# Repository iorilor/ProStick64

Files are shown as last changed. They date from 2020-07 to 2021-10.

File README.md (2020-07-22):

# ProStick64

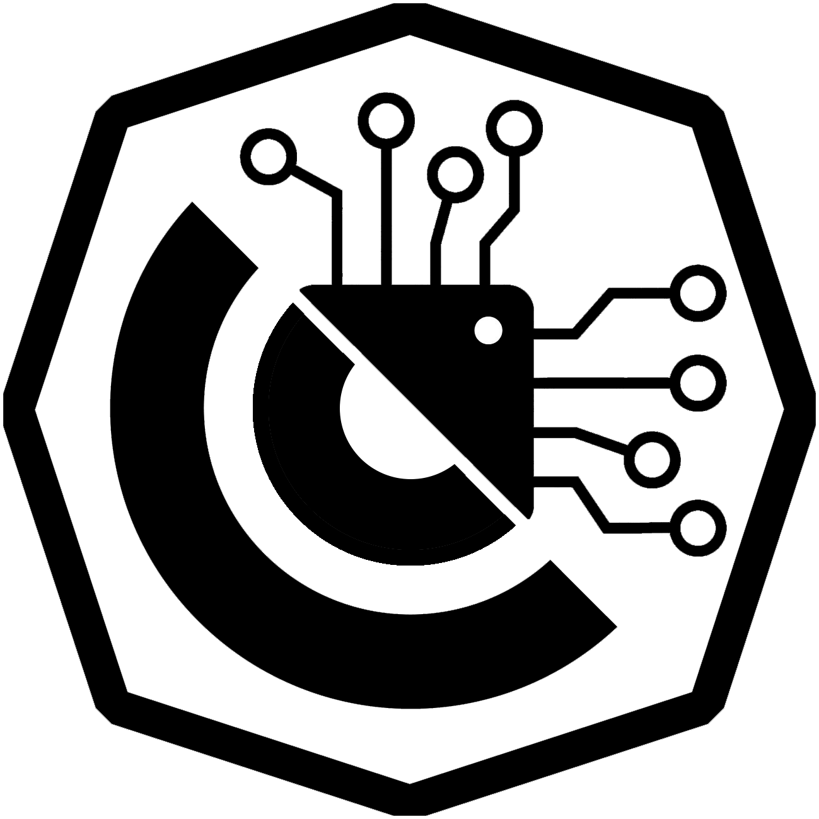
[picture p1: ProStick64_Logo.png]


This repository contains everything about the ProStick64 stick replacement module and more!
This is what you can find inside the various folders:
* datasheets:     datasheets of the various electronic components used on the board
* documentation:  useful documents and application notes regarding the STM32G0 MCU
* media:          Images and other media related to ProStick64
* PCB:            PCB gerber files, KICAD project and libraries
* render:         STL files of the enclosure and thumbstick
* source:         Source code of the software

Note: if you want to edit the source code I suggest you to import the source folders inside STM32CubeIDE software.
For any additional info contact me at info@prostick64.com

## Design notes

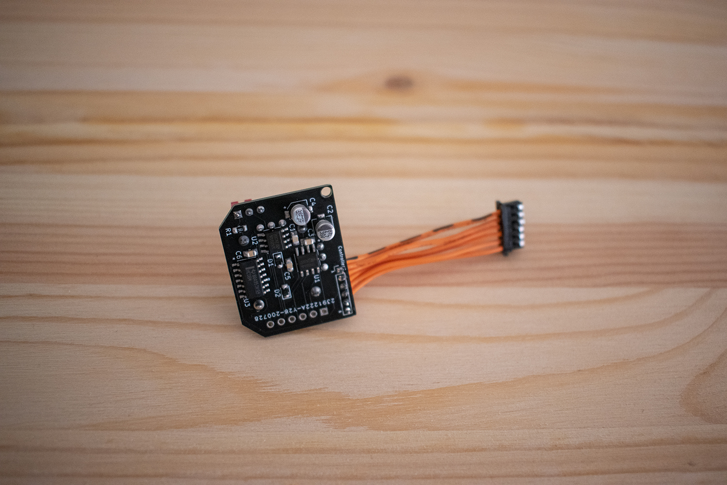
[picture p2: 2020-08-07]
media/v0_5/CUrear.jpg

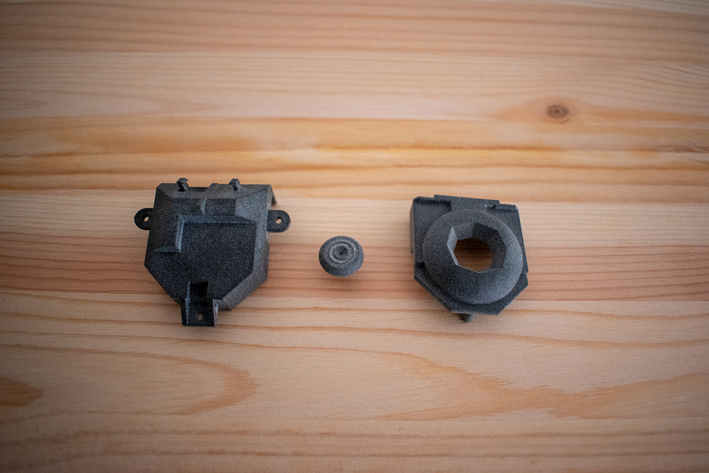
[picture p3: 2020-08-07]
media/v0_5/Case.jpg

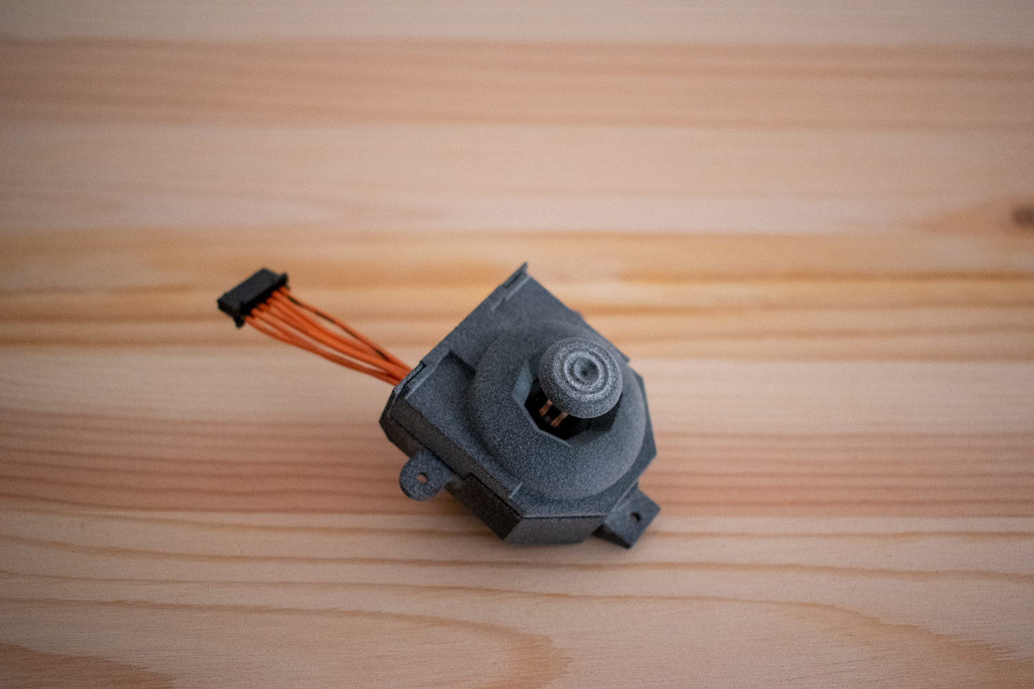
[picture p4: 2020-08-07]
media/v0_5/FullModule.jpg

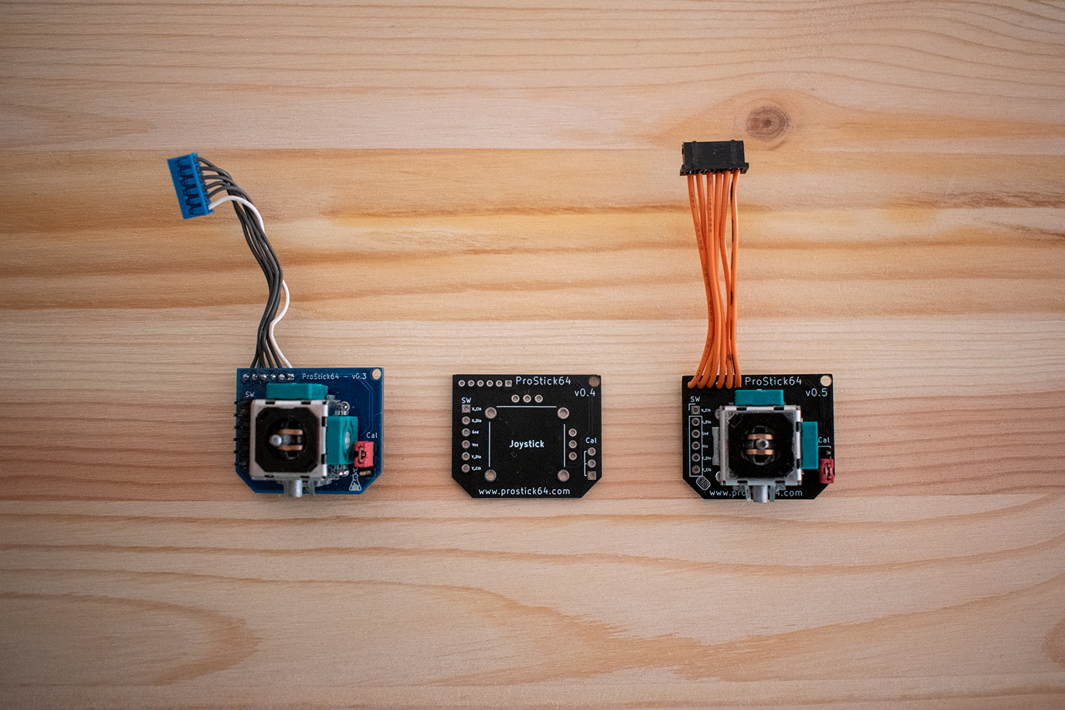
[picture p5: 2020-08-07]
media/v0_5/Front.jpg

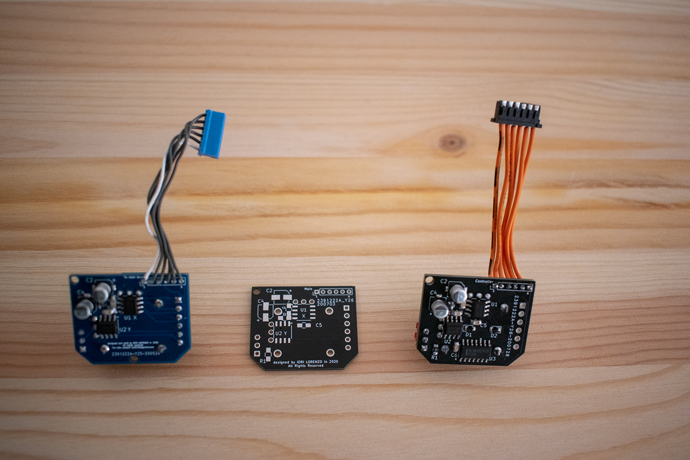
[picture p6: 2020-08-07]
media/v0_5/rear.jpg

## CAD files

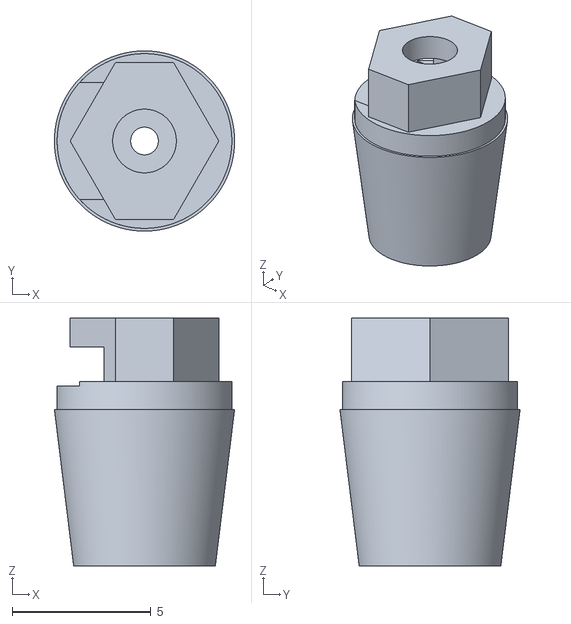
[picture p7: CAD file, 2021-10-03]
render/Stick_Shaft v5.stl
6.50 x 6.50 x 8.95

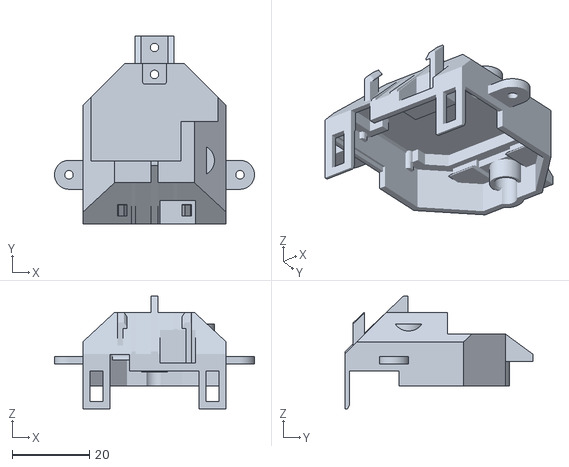
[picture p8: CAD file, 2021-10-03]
render/Enclosure Back v12.stl
51.7 x 48.7 x 29.2

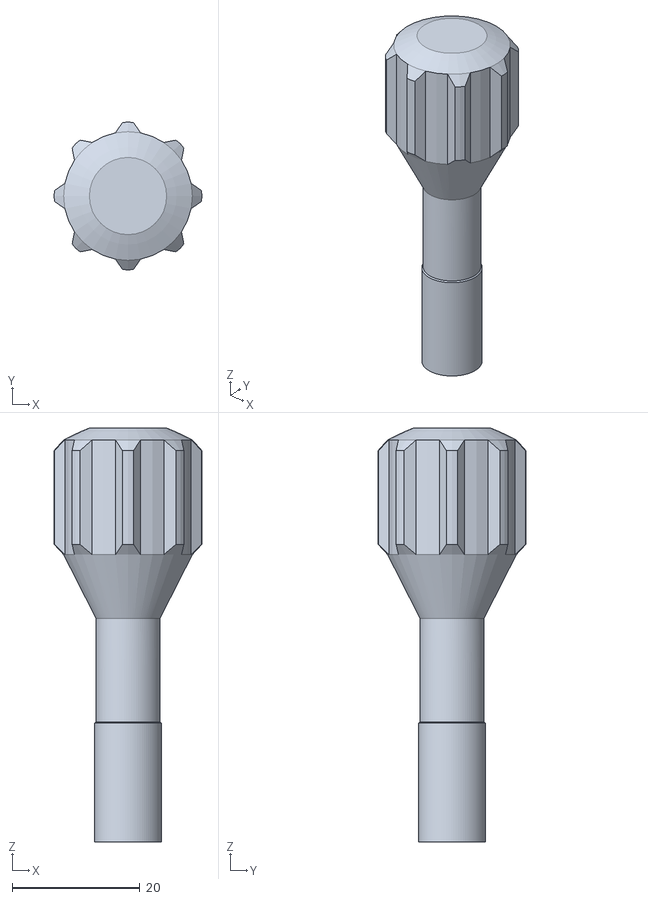
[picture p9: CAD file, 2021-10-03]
render/Bit Holder.stl
23.2 x 23.2 x 64.9

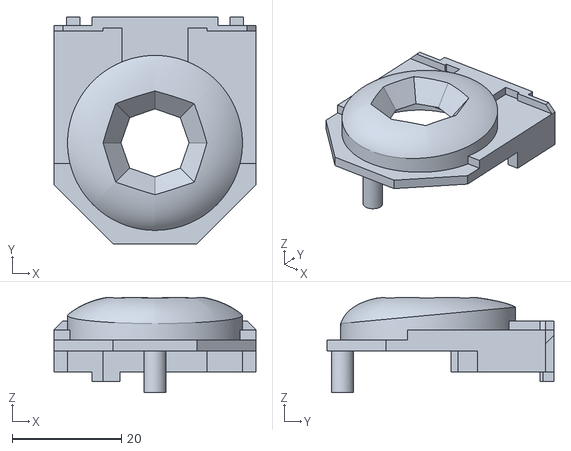
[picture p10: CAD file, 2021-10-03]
render/Enclosure Top v13.stl
37.0 x 41.5 x 17.4

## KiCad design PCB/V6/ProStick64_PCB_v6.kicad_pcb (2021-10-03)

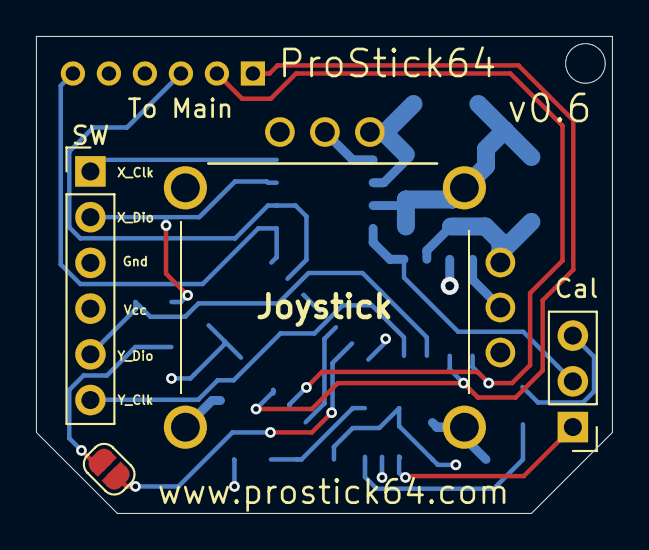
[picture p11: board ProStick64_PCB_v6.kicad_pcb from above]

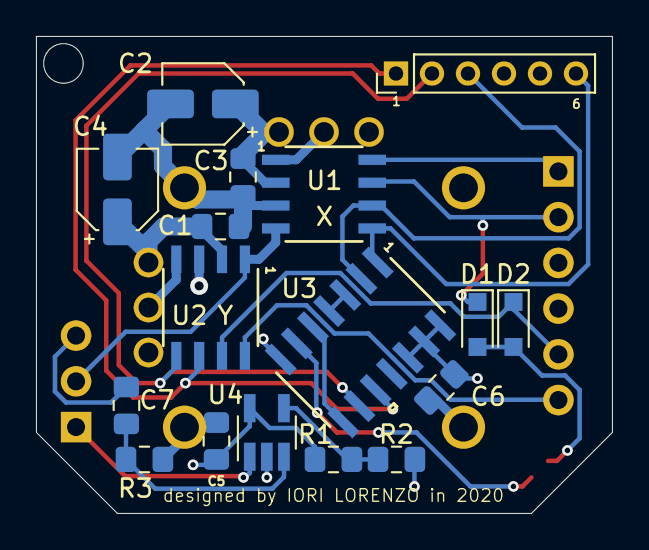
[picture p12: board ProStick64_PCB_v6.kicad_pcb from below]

Board: 4 copper layers, 32.0 x 26.5 mm, 21 parts (17 on the bottom side), 20 nets.

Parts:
C1, C3, C5, C6, C7: 0.1uF; C_0805_2012Metric_Pad1.15x1.40mm_HandSolder
C2, C4: 4.7uF; CP_Elec_4x5.3
Cal: CAL_SW; PinHeader_1x03_P2.54mm_Vertical
D1, D2: BAS316; D_SOD-323_HandSoldering
JP1: SolderJumper_2_Open; SolderJumper-2_P1.3mm_Open_RoundedPad1.0x1.5mm
Joystick: RKJXK122000D
R1: 4.75k; R_0805_2012Metric_Pad1.15x1.40mm_HandSolder
R2, R3: 30k; R_0805_2012Metric_Pad1.15x1.40mm_HandSolder
SW: Serial Wire; PinHeader_1x06_P2.54mm_Vertical
To Main: TO MAIN BOARD; PinHeader_1x06_P2.00mm_Vertical
U1: X; STM32G0_SO8_T2
U2: Y; STM32G0_SO8_T2
U3: CD74HC08M
U4: TS861AIL; SOT-23-5_HandSoldering

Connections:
/Vcc: C1.1, C2.1, C3.1, C4.1, C5.1, C6.1, C7.1, Cal.3, Joystick.3, Joystick.6, R1.2, SW.4, To Main.5, U1.2, U2.2, U3.12, U3.13, U3.14, U4.5
/X0: To Main.6, U1.5, U3.1
/X1: To Main.3, U1.6, U3.2
/Y0: To Main.2, U2.5, U3.9
/Y1: To Main.1, U2.6, U3.10
/cal: Cal.2, U1.4, U2.1
/x_dio: D1.1, SW.2, U1.7
/y_dio: D2.1, SW.5, U2.7
GND: C1.2, C2.2, C3.2, C4.2, C5.2, C6.2, Joystick.1, Joystick.4, Joystick.GND, R2.1, R3.2, SW.3, To Main.4, U1.3, U2.3, U3.7, U4.2
unnamed: C7.2, R3.1, U4.3
unnamed: D1.2, D2.2, JP1.1
unnamed: SW.1, U1.8
unnamed: SW.6, U2.8
unnamed: Cal.1, U4.1
unnamed: JP1.2, U3.6
unnamed: R1.1, R2.2, U4.4
unnamed: Joystick.2, U1.1
unnamed: Joystick.5, U2.4
unnamed: U3.3, U3.4
unnamed: U3.5, U3.8

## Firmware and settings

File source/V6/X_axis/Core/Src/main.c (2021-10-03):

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

/* Includes ------------------------------------------------------------------*/
#include "main.h"
#include "math.h"

/* USER CODE BEGIN PD */
#define MAX_RANGE    	83			//Maximum number of steps in every direction
#define MAX_RANGE_EXT 	100			//Maximum number of steps in every direction (ext)
#define DEADZONE      	250			//Area that will be ignored (0-2048)
#define AVG_PRECISION	128			//Number of averaged measurements for every getValue()
/* USER CODE END PD */

ADC_HandleTypeDef hadc1;

void SystemClock_Config(void);
static void MX_GPIO_Init(void);
static void MX_ADC1_Init(void);
/* USER CODE BEGIN PFP */
int16_t 	getCalFlashSlot		(void);
void 		calibration			(uint8_t, uint8_t);
void 		draw			    (int16_t);
void 		writeToFlash	  	(uint32_t, uint32_t, uint8_t);
void 		eraseFlash 		  	(void);
uint16_t 	getValue		    (void);
void		rotateLeft 		  	(volatile uint32_t*);
void		rotateRight 	  	(volatile uint32_t*);
void		swdioInput      	(void);
uint16_t	getValueKalman		(float*, float*, float*, float*);
void		kalWait				(uint16_t, float*, float*, float*, float*);

/* USER CODE END PFP */

/* USER CODE BEGIN 0 */
volatile uint32_t* FLASH_SR  	  = (uint32_t*)0x40022010;  //MEMORY ADDRESSES
volatile uint32_t* FLASH_CR  	  = (uint32_t*)0x40022014;
volatile uint32_t* PAGE15_SLOT1   = (uint32_t*)0x08007800;
volatile uint32_t* GPIOA_IDR 	  = (uint32_t*)0x50000010;
volatile uint32_t* GPIOB_IDR 	  = (uint32_t*)0x50000410;
volatile uint32_t* GPIOA_ODR 	  = (uint32_t*)0x50000014;
volatile uint32_t* ADC_ISR 		  = (uint32_t*)0x40012400;
volatile uint32_t* ADC_DR 		  = (uint32_t*)0x40012440;
/* USER CODE END 0 */

/**
  * @brief  The application entry point.
  * @retval int
  */
int main(void)
{
  /* MCU Configuration--------------------------------------------------------*/

  /*Reset of all peripherals, Initializes the Flash interface and the Systick.*/
  HAL_Init();

  /* Configure the system clock */
  SystemClock_Config();

  /* Initialize all configured peripherals */
  MX_GPIO_Init();
  MX_ADC1_Init();
  /* USER CODE BEGIN 2 */
  HAL_ADC_Start(&hadc1);
  //The next line configures the output register with the bit wheel
  *GPIOA_ODR = (*GPIOA_ODR & 0xFFFF0000) + 0x6600;
  uint16_t calSwRead = (uint16_t)(*GPIOA_IDR) & 0x1; //calSw = GPIOA_PIN0 status
  uint8_t  calSw = 0;
  if (calSwRead) calSw = 1;
  int16_t 	calFlashSlot = getCalFlashSlot();

  //If getCalFlashSlot returns -1 it means there is no calibration data stored
  if (calFlashSlot == -1) calibration(calSw, 0);

  //If it returns 255 it means the memory is full. Erase + calibration needed.
  if (calFlashSlot == 255){
    eraseFlash();
    calibration(calSw, 0);
  }
  uint32_t 	w1 = *(PAGE15_SLOT1 + ((calFlashSlot)*2));
  uint32_t 	w2 = *(PAGE15_SLOT1 + ((calFlashSlot)*2) + 1);
  uint16_t 	w1a = (uint16_t)(w1>>16);
  uint16_t 	neutral16 = (uint16_t) w1;
  uint16_t 	calFactAInt = (uint16_t)(w2>>16);
  uint16_t 	calFactBInt = (uint16_t) w2;
  uint16_t 	min = w1a & 0x7FFF;
  uint8_t  	calSwOld = (uint8_t)(w1a >> 15);
  if (calSwOld != calSw){
  	calFlashSlot++;
    calibration(calSw, (uint8_t)calFlashSlot);
  }
  float    	calFactA = (float)calFactAInt / 10000;
  float    	calFactB = (float)calFactBInt / 10000;

  uint16_t 	value16, value16Old, value16Raw;
  float		valueFloat = 0;
  int16_t 	steps = 0;
  uint16_t	stepScale = 0;
  value16Old = 2048;
  value16Raw = getValue();
  if (value16Raw < 1500 || value16Raw > 2500){
	  stepScale = 4096 / (MAX_RANGE_EXT * 2);
  } else {
	  stepScale = 4096 / (MAX_RANGE * 2);
  }
  HAL_Delay(1000);
    /* USER CODE END 2 */

    /* Infinite loop */
    /* USER CODE BEGIN WHILE */
    while (1)
    {
  	  value16Raw = getValue();
  	  if (value16Raw < neutral16){
  		  if (value16Raw < min) value16Raw = min;
  		  valueFloat = value16Raw - min;
  		  valueFloat = valueFloat * calFactA;
  		  if (valueFloat >= (2048 - DEADZONE)) valueFloat = 2048 - DEADZONE;
  		  valueFloat = (valueFloat / (2048 - DEADZONE)) * 2048;
  		  value16 = (uint16_t)valueFloat;
  	  }
  	  else if (value16Raw == neutral16)	value16 = neutral16;
  	  else if (value16Raw > neutral16){
  		  valueFloat = value16Raw - neutral16;
  		  valueFloat = valueFloat * calFactB;
  		  if (valueFloat <= (DEADZONE)) valueFloat = DEADZONE;
  		  valueFloat = ((valueFloat - DEADZONE)/(2048 - DEADZONE))*2048;
  		  value16 = (uint16_t)valueFloat + 2048;
  	  }
  	  if (value16 > 4096) value16 = 4096;
  	  if (value16 < 0) value16 = 0;
  	  steps = steps + ((int16_t)value16 - value16Old);
  	  value16Old = value16;
  	  while (steps < -stepScale){
  		  rotateLeft(GPIOA_ODR);
  		  steps = steps + stepScale;
  	  }
  	  while (steps > stepScale){
  		  rotateRight(GPIOA_ODR);
  		  steps = steps - stepScale;
  	  }

    /* USER CODE END WHILE */

    /* USER CODE BEGIN 3 */
  }
  /* USER CODE END 3 */
}

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
/* USER CODE BEGIN 4 */

//Find the FLASH memory slot currently in use
int16_t getCalFlashSlot(void){
	int16_t i = 0;
	uint32_t data = *PAGE15_SLOT1;
	while (((data != 0xFFFFFFFF) && i < 256)){
		i++;
		data = *(PAGE15_SLOT1 + i*2);
	}
	return i-1;
}
//Calibration 4.0
void calibration(uint8_t calSw, uint8_t calFlashSlot){

//PHASE 1 - Calculating neutral value
uint32_t 	i=0, neutral32=0, w1=0xFFFFFFFF,w2=0xFFFFFFFF;
uint16_t 	value16=0, count=0, neutralAverage=0, neutralAverageOld=0;
uint16_t  	max=0, min=0, MCU_OK=0;
uint16_t 	w1a=0xFFFF, w1b=0xFFFF, w2a=0xFFFF, w2b=0xFFFF;
uint8_t		neutralOK=0;
int8_t		dir=0;
float		calFactA=0.0, calFactB=0.0;

//Kalman filter variables definition
float 		kal_est_e = 2.0, kal_mea_e = 2.0, kal_q = 0.01;
float		kal_last_est = (float) getValue();

HAL_Delay(5000);

swdioInput();

//Set GPIOA_PIN11 and PIN12 HIGH to communicate that MCU is ready to proceed
*GPIOA_ODR = (*GPIOA_ODR & 0xFFFF0000) + 0x1800;

//Wait until GPIOA_PIN13 becomes 1 - both MCUs are ready to proceed
i=0;
while (i<1000){
	while (!MCU_OK){
		i=0;
		MCU_OK = (uint16_t)(*GPIOA_IDR) & 0x2000;
	}
	i++;
	HAL_Delay(1);
	MCU_OK = (uint16_t)(*GPIOA_IDR) & 0x2000;
}
kalWait(700, &kal_est_e, &kal_mea_e, &kal_last_est, &kal_q);

//The next line reconfigures the output register with the bit wheel
*GPIOA_ODR = (*GPIOA_ODR & 0xFFFF0000) + 0x6600;

MCU_OK = 0;
draw(3);

value16 = getValueKalman(&kal_est_e, &kal_mea_e, &kal_last_est, &kal_q);

while (value16<1600 || value16>2400){   //Wait for joystick to be centered
	value16 = getValueKalman(&kal_est_e, &kal_mea_e, &kal_last_est, &kal_q);
}
//Step 1.1 - Pull the stick to any corner and let go until neutral is OK
while (neutralOK<3){
	count++;
	while (value16>1500 && value16<2500){  //Wait for joystick to be moved
		value16 = getValueKalman(&kal_est_e, &kal_mea_e, &kal_last_est, &kal_q);
	}
	kalWait(1300, &kal_est_e, &kal_mea_e, &kal_last_est, &kal_q);
	value16 = getValueKalman(&kal_est_e, &kal_mea_e, &kal_last_est, &kal_q);
	if (value16>2500) dir=1;
	else if (value16<1500) dir=-1;
	while (value16<1600 || value16>2400){  //Wait for joystick to return centered
		value16 = getValueKalman(&kal_est_e, &kal_mea_e, &kal_last_est, &kal_q);
	}
	kalWait(1300, &kal_est_e, &kal_mea_e, &kal_last_est, &kal_q);	//Wait for spring to stabilize
	value16 = getValueKalman(&kal_est_e, &kal_mea_e, &kal_last_est, &kal_q);
	neutral32 = neutral32 + value16;	 //Add current neutral reading to pool
	neutralAverage = (neutral32/count);
	if (neutralAverage == neutralAverageOld) neutralOK++;
	else neutralOK = 0;
	neutralAverageOld = neutralAverage;
	if (dir==1) 		draw(-2);
	else if (dir==-1) 	draw(-3);
}
//Set GPIOA_PIN11 and PIN12 HIGH to communicate that MCU is ready to proceed
*GPIOA_ODR = (*GPIOA_ODR & 0xFFFF0000) + 0x1800;

//Wait until GPIOA_PIN13 becomes 1 - both MCUs are ready to proceed
i=0;
while (i<1000){
	while (!MCU_OK){
		i=0;
		MCU_OK = (uint16_t)(*GPIOA_IDR) & 0x2000;
	}
	i++;
	HAL_Delay(1);
	MCU_OK = (uint16_t)(*GPIOA_IDR) & 0x2000;
}

kalWait(700, &kal_est_e, &kal_mea_e, &kal_last_est, &kal_q);

//The next line reconfigures the output register with the bit wheel
*GPIOA_ODR = (*GPIOA_ODR & 0xFFFF0000) + 0x6600;

MCU_OK = 0;
draw(3);
//PHASE 2 - Calculating min and max while the stick is rotated
min = neutralAverage;
max = neutralAverage;
for (i=0; i<100000; i++){
	value16 = getValueKalman(&kal_est_e, &kal_mea_e, &kal_last_est, &kal_q);
	if (value16 > max){
		max = value16;
	}else if(value16 < min){
		min = value16;
	}
}
//PHASE 3 - Calculating calFactA and calFactB
calFactA = ((float)2047) / (neutralAverage - min);
calFactB = ((float)2048) / (max - neutralAverage);
//PHASE 4 - Calculating w1 and w2 and write to flash
/* Calibration data structure:

	w1 = 						w1a								  w1b
				|--1bit--|---------15bit----------|---------------16bit---------------|
				  calSw				min							neutral16

	w2 =						w2a									w2b
				|--------------16bit--------------|---------------16bit---------------|
							 calFactA							calFactB
*/
w1a = min + ((uint16_t)calSw << 15);
w1b = neutralAverage;
w2a = (uint16_t)(calFactA * 10000);
w2b = (uint16_t)(calFactB * 10000);
w1 = ((uint32_t)w1a << 16) + w1b;
w2 = ((uint32_t)w2a << 16) + w2b;
writeToFlash(w1, w2, calFlashSlot);

//Set GPIOA_PIN11 and PIN12 HIGH to communicate that MCU is ready to proceed
*GPIOA_ODR = (*GPIOA_ODR & 0xFFFF0000) + 0x1800;

//Wait until GPIOA_PIN13 becomes 1 - both MCUs are ready to proceed
i=0;
while (i<1000){
	while (!MCU_OK){
		i=0;
		MCU_OK = (uint16_t)(*GPIOA_IDR) & 0x2000;
	}
	i++;
	HAL_Delay(1);
	MCU_OK = (uint16_t)(*GPIOA_IDR) & 0x2000;
}

HAL_Delay(100);

//The next line reconfigures the output register with the bit wheel
*GPIOA_ODR = (*GPIOA_ODR & 0xFFFF0000) + 0x6600;

MCU_OK = 0;
draw(-1);
}

//Move the cursor in a waving pattern for n times
void draw(int16_t n){
	uint8_t  i=0;
  uint16_t j=0;
  //if times_to_repeat = -1 loop indefinitely
  if (n == -1){
    while(1){
      for (i=0; i<40; i++){
  			rotateRight(GPIOA_ODR);
  			HAL_Delay(1);
  		}
  		HAL_Delay(500);
  		for (i=0; i<40; i++){
  			rotateLeft(GPIOA_ODR);
  			HAL_Delay(1);
  		}
  		for (i=0; i<40; i++){
  			rotateLeft(GPIOA_ODR);
  			HAL_Delay(1);
  		}
  		HAL_Delay(500);
  		for (i=0; i<40; i++){
  			rotateRight(GPIOA_ODR);
  			HAL_Delay(1);
  		}
    }
  }
  //if times_to_repeat = -2 perform a quick draw cycle to the right
  if (n == -2){
		  for (i=0; i<20; i++){
			  rotateRight(GPIOA_ODR);
			  HAL_Delay(1);
		  }
		  HAL_Delay(100);
		  for (i=0; i<20; i++){
			  rotateLeft(GPIOA_ODR);
			  HAL_Delay(1);
		  }
  }
  //if times_to_repeat = -3 perform a quick draw cycle to the left
  if (n == -3){
 		  for (i=0; i<20; i++){
 			  rotateLeft(GPIOA_ODR);
 			  HAL_Delay(1);
 		  }
 		  HAL_Delay(100);
 		  for (i=0; i<20; i++){
 			  rotateRight(GPIOA_ODR);
 			  HAL_Delay(1);
 		  }
   }
  //otherwise loop n times
  else {
  	for (j=0; j<n; j++){
  		for (i=0; i<40; i++){
  			rotateRight(GPIOA_ODR);
  			HAL_Delay(1);
  		}
  		HAL_Delay(500);
  		for (i=0; i<40; i++){
  			rotateLeft(GPIOA_ODR);
  			HAL_Delay(1);
  		}
  		for (i=0; i<40; i++){
  			rotateLeft(GPIOA_ODR);
  			HAL_Delay(1);
  		}
  		HAL_Delay(500);
  		for (i=0; i<40; i++){
  			rotateRight(GPIOA_ODR);
  			HAL_Delay(1);
  		}
  	}
  }
}

//Write data into MCU flash memory
void writeToFlash(uint32_t w1, uint32_t w2, uint8_t calFlashSlot){

	HAL_FLASH_Unlock();
	while (*FLASH_SR&(1<<16));          			    //wait for BSY1 flag to be 0
	*FLASH_SR = *FLASH_SR & 0x00050000; 			    //reset all flash error flags
	while (*FLASH_SR&(1<<18));          			    //wait for CFGBSY1 flag to be 0
	*FLASH_CR = *FLASH_CR | 0x01; 					      //set PG flag
	*(PAGE15_SLOT1 + (calFlashSlot*2)) = w1;      //write w1 into Flash
	__ISB();				//Ensures that the two 32bit words are not merged by compiler
	*(PAGE15_SLOT1 + (calFlashSlot*2) + 1) = w2;  //write w2 into Flash
	while (*FLASH_SR&(1<<16));          			    //wait for BSY1 flag to be 0
	while (*FLASH_SR&(1<<18));          			    //wait for CFGBSY1 flag to be 0
	*FLASH_CR = *FLASH_CR & 0xFFFFFFFE;			     	//reset PG flag
	HAL_FLASH_Lock();
}

//Erase all data in pages 15 and 16 of MCU flash memory
void eraseFlash (void){
	HAL_FLASH_Unlock();
	while (*FLASH_SR&(1<<16));          	//wait for BSY1 flag to be 0
	*FLASH_SR = *FLASH_SR & 0x00050000; 	//reset all flash error flags
	*FLASH_CR = *FLASH_CR & 0xC0000000; 	//reset page erase and number flags
	*FLASH_CR = *FLASH_CR | 0x7A; 				//set page erase flag and page number 15
	*FLASH_CR = *FLASH_CR | (1<<16);    	//set start flag
	while (*FLASH_SR&(1<<16));          	//wait for BSY1 flag to be 0
	*FLASH_CR = *FLASH_CR & 0xC0000000; 	//reset page erase and number flags
	HAL_FLASH_Lock();
}

//Wait till new value is available from ADC data register and read it
uint16_t getValue(void){
  uint32_t value = 0;
  uint16_t i;
  for (i=0; i<AVG_PRECISION; i++){
	while (!(*ADC_ISR & 1<<3));
	value = value + (uint16_t)(*ADC_DR);
  }
  value = value / AVG_PRECISION;
  return (uint16_t) value;
}

//Simulate an optical disc rotation (LEFT)
void rotateLeft (volatile uint32_t* GPIOA_ODR){
	uint8_t result, data;
	data = (uint8_t)(*(GPIOA_ODR)>>8);
	if ( data & 1<<7 ){
		result = (data<<1)|(1<<0);
	}else{
		result = (data<<1);
	}
	*GPIOA_ODR = (*GPIOA_ODR & 0xFFFF00FF) + ((uint16_t)result << 8);
}

//Simulate an optical disc rotation (RIGHT)
void rotateRight (volatile uint32_t* GPIOA_ODR){
	uint8_t result, data;
	data = (uint8_t)(*(GPIOA_ODR)>>8);
	if ( data & (1<<0) ){
		result = (data>>1)|(1<<7);
	}else{
		result = (data>>1);
	}
	*GPIOA_ODR = (*GPIOA_ODR & 0xFFFF00FF) + ((uint16_t)result << 8);
}

//Configure SWDIO pin (GPIOA_PIN13) as input
void swdioInput (void){
  GPIO_InitTypeDef GPIO_InitStruct = {0};
  GPIO_InitStruct.Pin  = GPIO_PIN_13;
  GPIO_InitStruct.Mode = GPIO_MODE_INPUT;
  GPIO_InitStruct.Pull = GPIO_PULLDOWN;
  HAL_GPIO_Init(GPIOA, &GPIO_InitStruct);
}

uint16_t getValueKalman(float* est_e, float* mea_e, float* last_est, float* q){

	float kal_gain, est;

	kal_gain = (*est_e) / ((*est_e) + (*mea_e));
	est = (*last_est) + (kal_gain * (getValue() - (*last_est)));
	(*est_e) = ((1.0 - kal_gain) * (*est_e)) + (fabs((*last_est) - est) * (*q));
	(*last_est) = est;
	return (uint16_t)(est + 0.5);
}

void kalWait(uint16_t times, float* est_e, float* mea_e, float* last_est, float* q){
	uint16_t i;
	for (i=0; i<times; i++){
	getValueKalman(est_e, mea_e, last_est, q);
	}
}

/* USER CODE END 4 */
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


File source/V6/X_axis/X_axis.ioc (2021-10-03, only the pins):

Mcu.UserName=STM32G031J6Mx
PA0.GPIO_Label=CAL_SW
PA0.Signal=GPIO_Input
PA13.Signal=SYS_SWDIO
PA14-BOOT0.Signal=SYS_SWCLK
PB7.GPIO_Label=AXIS_IN
PB7.Signal=ADC1_IN11

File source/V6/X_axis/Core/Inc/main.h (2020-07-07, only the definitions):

#define AXIS_IN_Pin GPIO_PIN_7
#define AXIS_IN_GPIO_Port GPIOB
#define CAL_SW_Pin GPIO_PIN_0
#define CAL_SW_GPIO_Port GPIOA
#define OUT_0_Pin GPIO_PIN_11
#define OUT_0_GPIO_Port GPIOA
#define OUT_1_Pin GPIO_PIN_12
#define OUT_1_GPIO_Port GPIOA

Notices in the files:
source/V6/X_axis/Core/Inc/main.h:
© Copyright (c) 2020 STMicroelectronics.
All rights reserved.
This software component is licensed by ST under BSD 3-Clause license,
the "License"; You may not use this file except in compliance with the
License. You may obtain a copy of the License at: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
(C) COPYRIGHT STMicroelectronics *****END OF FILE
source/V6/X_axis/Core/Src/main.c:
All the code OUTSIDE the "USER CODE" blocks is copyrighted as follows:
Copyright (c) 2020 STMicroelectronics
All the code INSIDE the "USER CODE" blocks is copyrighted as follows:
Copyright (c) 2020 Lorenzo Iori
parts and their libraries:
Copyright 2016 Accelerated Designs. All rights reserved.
